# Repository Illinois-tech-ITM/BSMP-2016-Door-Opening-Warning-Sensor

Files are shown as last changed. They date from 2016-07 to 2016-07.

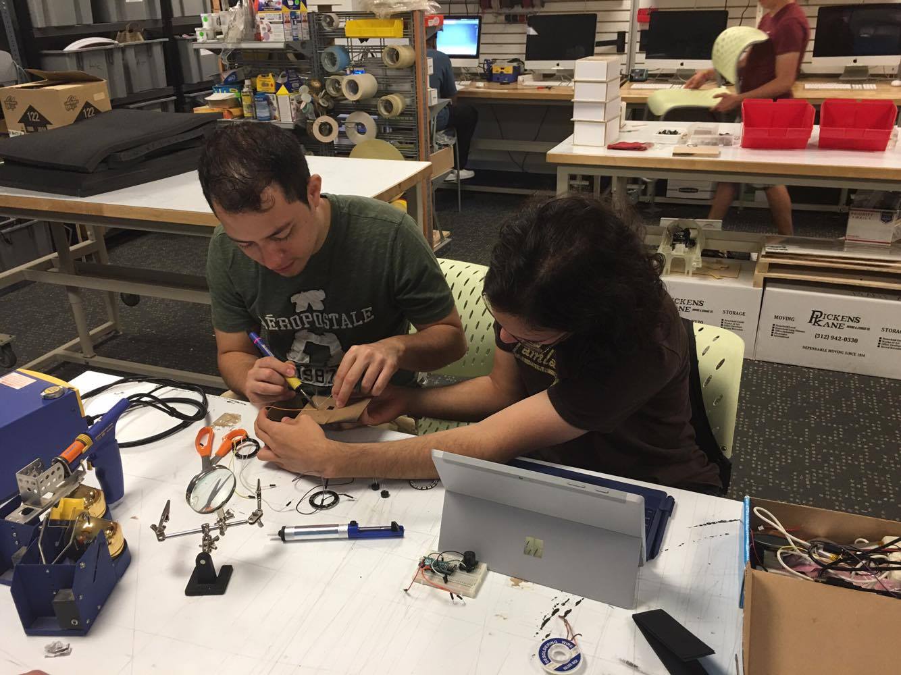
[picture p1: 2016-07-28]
Documents/Case Fabrication_2.jpg

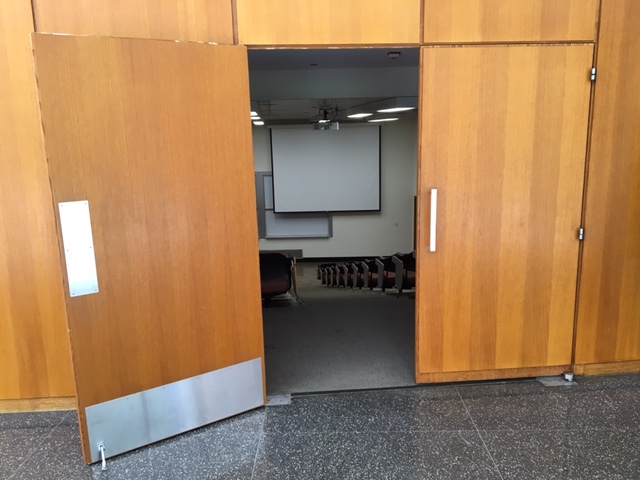
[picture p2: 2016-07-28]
Documents/Operating Door.jpg

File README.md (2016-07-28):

# BSMP-2016-Door-Opening-Warning-Sensor

This repo contains the code and schematics for creating an early warning system for people walking in creating an early warning system for doors opening into hallways

---------------------
### Participants
* Gabriel Filipe Botelho Barbosa ([@bestknighter](https://github.com/bestknighter))
* Guilherme de Castro ([@guidecastro](https://github.com/guidecastro))
* Luiz Gustavo de Marchi Brito
* Matheus Braz Duque
* Rodrigo Ferreira Abdulmassih

---------------------
### Instructions
If you want to reproduce this project, follow the steps below.

1. Download an Arduino IDE of your preference (we used their [official one](http://www.arduino.cc))
2. Build the project as in the [Fritzing diagram](/Documents/Diagram.png). _If you don't have a solar panel, you can ignore the solar panel charger and simply power it through the micro-usb._
3. Open the [main code](/Arduino_Micro_Code/Arduino_Micro_Code.ino) in the IDE.
4. Build and upload it. __Make sure to set the correct arduino model before uploading.__

You can tweak with the constants declared as Macros to calibrate the project for your use. The values in this repo is the one that worked best with us.

##### _Troubleshooting_

Problem | Solution | Reason
------ | ------- | --------
I uploaded the code and it is running excruciatingly slow/not running at all | If you're running with an external power, build the production version (comment all DEBUG defines). If you're powering with PC usb, open a serial monitor | This happens because the arduino waits the serial port to be read, halting the program until done so or until timeout (which takes usually too long)
Buzzer sounds but LEDs don't/LEDs lights up but buzzer don't | Check your cables to see if they are firmly attached, or change them, and plugged in to the right port described in the Macro areas | The signal may not be reaching the component due to a broken cable, loose cable or wrong port
Alarm does not behave as expected/is weird. | Callibrate your system by building the DEBUG version (uncomment just the `#define DEBUG`) and changing the constants. | Your case/scenario may be different from ours. Activating the debug mode allows you to understand what is happening and then change the constants value to what may fit best.

##### _Known Issues_
* When the distance with no one in front of the sensor is smaller than 2.5m and then someone enters (making the detected distance quickly reduce) is understood as someone walking towards the door, thus, triggering the alarm.
* The solar panel by itself can power the system and when the battery is charged can also power the system for a long time. But when the battery is plugged to the solar panel and powering the system, it stops working quickly. Using a power bank to power the system also works for a long time.

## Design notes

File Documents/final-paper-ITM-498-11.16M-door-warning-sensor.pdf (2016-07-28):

Illinois Institute of Technology School of Applied Technology Brazil Scientific Mobility Program

## Door Opening Warning Sensor

### 498UG Research Immersion Team

Prof. Jeremy Hajek

Gabriel Filipe Botelho Barbosa

Guilherme de Castro

Luiz Gustavo de Marchi Brito

Matheus Braz Duque

Rodrigo Ferreira Abdulmassih

Illinois Institute of Technology School of Applied Technology Brazil Scientific Mobility Program

Final Project report, Summer Research Program at Illinois Institute of Technology,

program provided and sponsored by the Brazilian government in

partnership with Institute of International Education.

### Door Opening Warning Sensor

Prof. Jeremy Hajek

Report regarding project research developed

by five Brazilian students during the period of

June 5 to July 26.

Illinois Institute of Technology School of Applied Technology Brazil Scientific Mobility Program

Summary

9. Personal Impressions

Illinois Institute of Technology School of Applied Technology Brazil Scientific Mobility Program

Introduction

Unfortunately, the media always emphasizes how safety matters are taken for granted

in the industry. It is not different when it comes to common areas or constructions, such as

houses, shopping centers and even university buildings.

Service doors, swinging or revolving, play a major role in domestic and industry

accidents. According to the U.S. Department of Labor’s Bureau of Labor Statistics, 17,800

non-fatal workplace door accidents were reported in 2003. Even though the safety regulations

are becoming stricter, from 2003 to nowadays, many accidents regarding service doors still

occurred.

It is known how fast Illinois Institute of Technology projects are growing and

consequently, the amount of people walking around campus and inside the buildings are

increasing as well. These facts draw attention to safety matters inside the facilities in order to

provide a harmless and efficient work environment.

The Wishnick Hall, built in 1945, is place of many events, seminars and presentations,

containing five classrooms and one auditorium. Throughout the years, the community noticed

that both doors, which give access to the auditorium, are not necessarily safe.

Both service doors are made of wood and are consequently heavy. The major issue is

how fast they open, due to an opening system. Consequently, many people have been injured

when walking outside the auditorium by the door.

The Door Opening Warning Sensor seeks to solve this human factor issue by

proposing and implementing a warning sensor inside the auditory, using a solar panel as its

energy source. The device would detect people inside and warn people outside, enhancing the

safety matter at Wishnick Hall.

Illinois Institute of Technology School of Applied Technology Brazil Scientific Mobility Program

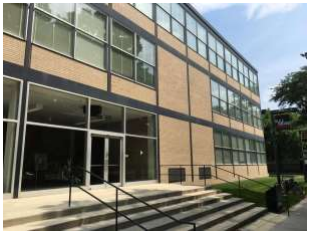
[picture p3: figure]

Figure 1 – Wishnick Hall at Illinois Institute of Technology campus.

Illinois Institute of Technology School of Applied Technology Brazil Scientific Mobility Program

Objectives

As the project title tells itself, the main objective is to propose a solution to the safety

matter at the auditorium of Wishnick Hall Auditorium. As explained in the introduction

section, when it comes to provide a harmless working environment, efforts should not be

measured.

The idea is to design and execute the further implementation of a warning sensor for

both auditory doors. Using a presence sensor, the device, as it detects a person approaching

the door, would emit a signal in order to warn people outside. The warning, searching for

maximum human factor efficiency, will be visual and audible as well.

Additionally, in order to achieve the community needs for environmentally friendly

systems, the whole warning device will be powered by solar panel. The project also includes,

as an objective, a study of how the glass, specifically the one used in the mentioned building,

influences the solar panel efficiency is providing the necessary energy to the warning device.

Illinois Institute of Technology School of Applied Technology Brazil Scientific Mobility Program

Materials list

Item | Quantity | Value per Item | Total Value per Item | Description
Solar panel | 1 | $29.00 | $29.00 | Medium 6V 2W Solar panel - 2.0 Watt
Controller | 1 | $24.95 | $24.95 | Arduino Micro with Headers - 5V 16MHz - (ATmega32u4 - assembled)
Charger | 1 | $17.50 | $17.50 | USB / DC / Solar Lithium Ion/Polymer charger
Tiny breadboard | 1 | $4 | $4
Half-size breadboard | 1 | $5.00 | $5.00
Battery | 1 | $9.95 | $9.95 | Lithium Ion Polymer Battery - 3.7v 1200mAh
Ultrasonic Distance Sensor | 1 | $29.99 | $29.99 | Parallax 28015 - Rev C
RGB Led ring | 3 | $9.95 | $29.85 | NeoPixel Ring - 16 x 5050 RGB LED with Integrated Drivers
Piezo Buzzer | 3 | $1.50 | $4.50 | Piezo Buzzer - PS1240
| | Total | $154.74

Table 1.0 – Material list, all taken from the Smart Technology & Embedded Systems Lab.

Table 2.0 – Material list, all taken from IDEA Shop, at IIT Campus.

Item | Quantity | Value
Used boxes | 2 | $0.00
Black paint spray | - | $0.00
General wires | - | $0.00
General tapes | - | $0.00
Flat cable | - | $0.00
Screws | 3 | $0.00

Illinois Institute of Technology School of Applied Technology Brazil Scientific Mobility Program

Solar Panel Experiment

Seeking to attend the global tendencies of renewable energy systems, the warning

sensor uses a solar panel, which model was specified in the Material List section of this

report. Due to logistics reasons and attempting to reduce the usage of extended wires along

the construction, the solar panel shall be installed inside the building.

To produce energy with a photovoltaic panel we need to mount the panel directed to

the sun. The process is simple, when the photons (particles of sunlight) hits the panel a certain

portion of it is absorbed within the semiconductor material. This means that the energy of the

absorbed light is transferred to the semiconductor. The energy knocks electrons loose,

allowing them to flow freely.

This project demand requires a study of how the glass, which separates the outside

area from the inside are of the building, affects the solar panel efficiency. Said that, a one-day

experiment was performed in order to measure the glass attenuation regarding the solar

radiation.

Starting at 8 am to 8 pm, running a step the experiment approximately each 3 hours,

the electric current and voltage were measured in a specific location inside and outside the

building.

The solar panel and multimeter, which models are specified in the Material List as

well, were used in order to collect the data shown in table 1 and 2 below. It is notable how the

average electric current and voltage varies within time of day and by the glass parameters.

Illinois Institute of Technology School of Applied Technology Brazil Scientific Mobility Program

Table 4.0 – Collected data, solar panel installed inside the building.

Analyzing the plotted charts, the expectations, based on the papers and studies

analyzed previous to the experiment, were accomplished. Right below, the electric current

data is shown for both cases of solar panel installation.

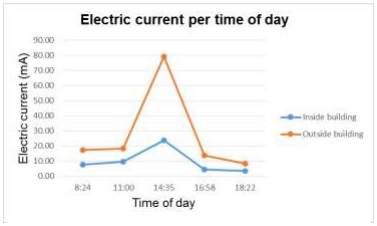
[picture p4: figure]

On the other hand, figure 3 shows how the voltage varies among time of day and

compare its values when the solar panel is located inside or outside the building.

Table 3.0 – Collected data, solar panel installed outside the building.

Experiment # | Time of day | Voltage (V) | Electric current (mA) | Standard Deviation
1 | 8:20 | 5.75 | 7.48 | 1.22
2 | 11:15 | 5.93 | 9.46 | 0.43
3 | 14:07 | 6.35 | 23.52 | 1.49
4 | 17:05 | 5.53 | 4.37 | 0.13
5 | 18:30 | 5.46 | 3.24 | 0.15
Experiment # | Time of day | Voltage | Average | Standard Deviation
1 | 8:24 | 6.29 | 17.18 | 2.36
2 | 11:00 | 6.22 | 18.23 | 0.29
3 | 14:35 | 6.83 | 79.22 | 6.66
4 | 16:58 | 5.96 | 13.52 | 0.89
5 | 18:22 | 5.86 | 8.17 | 0.35

Figure 2 – Comparison of electric current, provided by the solar panel, inside and outside the building.

Illinois Institute of Technology School of Applied Technology Brazil Scientific Mobility Program

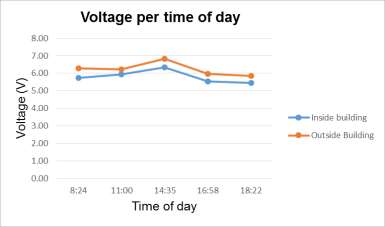
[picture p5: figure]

From the experiment, it is proved that the window’s glass really influenced the energy

production by the solar panel. This effect happened because the glass used on windows

nowadays receives special treatment to improve their ultraviolet and infrared reflections. This

glass is known as Low-emissivity Glass, and according to the U.S. Department of Energy it

has the capability to decrease up to 70% the heat provided by the sun.

That being said, it is confirm that when it comes to solar panels, more light means

more energy. As expected, experimental results showed that the solar panel, while installed

inside the building, achieved approximately 35% of capability to produce energy compared to

the installation outside the building.

Figure 3 – Comparison of voltage, provided by the solar panel, inside and outside the building.

Illinois Institute of Technology School of Applied Technology Brazil Scientific Mobility Program

Solar Panel

An experiment, which objective was to verify if the solar panel provides enough

power to the sensor system, was performed in the laboratory. A power source with variable

voltage setup was used in order to simulate the solar panel. A voltage of 6 V was settled in the

variable power source, based on the average voltage provided by the solar panel.

After soldering the capacitor on the Solar LiPoly Charger v2.0, which receives the

tension from the power source and distribute it to the battery and sensor system, the power

source was linked to the laboratory electrical system. Using a multimeter, it was verified that

6.2 V and 4.24 were distributed to the sensor system and battery, respectively.

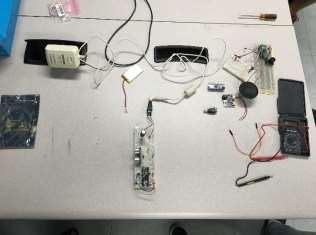
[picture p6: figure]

At first, even though the whole system was attached to the electrical system, the sensor

experienced an unstable period. The buzzer identified this stage, sonorously indicating that

the sensor was detecting someone even thought there was anyone on its range. After a while,

approximately 5 minutes later, the system started to work as expected. The most reasonable

explanation for that fact is the battery, which faced an unstable charging period and

consequently, the whole system was compromised for that period.

Figure 4 – Experimental apparatus and disposition.

Illinois Institute of Technology School of Applied Technology Brazil Scientific Mobility Program

Conclusively, based on this presented test and the last one, which verified that the

solar panel is capable of providing, in average, 6 V to the system, one solar panel is enough to

electrically feed the whole warning system.

Illinois Institute of Technology School of Applied Technology Brazil Scientific Mobility Program

Algorithm

### 1. Code progression through the project

One of the most important requirements of this project is to be responsive. The latency

between the distance between the sensor and the person needs to reflect as fast as possible in

the alarm. This yields in two main constraints code-wise: The distance sampling needs to

happen quite often and the decision of activating or deactivating the alarm needs also.

In our first iteration, we used a simple threshold for activating the alarm (i.e., if the

distance is smaller than X, activate the alarm, deactivate otherwise) and a direct sensor

sampling (i.e., the detected distance is considered to be absolute truth and taken without

noise). This first version met the constraints but not the requirements. The code executed

really fast and the alarm activated/deactivated immediately, but this was far from what we

needed. Not because it wasn’t fast enough, but because there were noise. Lots of noise. If

someone stood still in a specific distance, the alarm would activate and deactivate several

times per second.

Our approach was to use the libraries available to us made by the manufactures of our

components and hysteresis in the threshold. Those libraries exposed to us several methods for

noise handling. At this point, our code was somewhat usable enough to start calibrating to get

the specific values for our test case. This values are the maximum distance to trigger the

alarm, size of the hysteresis, amount of noise reduction needed, etc.

As we were measuring for the first time, we noticed that we went to the other side of

the scale, now having a really slow sampling code but with good decisions. After some brute-

force debugging we found the issue: the libraries was executing a blocking code. To be able to

Illinois Institute of Technology School of Applied Technology Brazil Scientific Mobility Program

deal with the noise, the library was sampling the distance several consecutive ways, then

calculating the mean, and then returning the control to the rest of the code. This was

consuming a lot of the time that could be used to calculate whether or not to activate the

alarm.

In the third code iteration, we decided to sample the sensor with no noise at all and

write our own non-blocking noise reduction code. We also added a control state to know the

direction of the movement of the person and we already wrote this with hysteresis. After some

testing to determine the intensity of the noise reduction algorithm, we had a robust, fast and

efficient algorithm that could not only do what we needed to do but also do it in a small

amount of time.

The next step would be to do a code cleanup to reduce the size (removing unused

libraries and only importing the functions used), refactor it to separate the algorithm that

decides what to do from the algorithm that turns on or off the alarm, using hardware

interruptions for distance sampling and optimize the non-blocking code further to have fewer

time-consuming assembly operations (e.g., instead of moving the whole queue to add a new

sampled distance, just replace the older one).

### 2. Algorithm overview

First of all, to reduce Arduino’s RAM usage, our constants are Macros defined in the

header. The downside is the increased compilation time, but nothing too much to be

impossible to wait.

Illinois Institute of Technology School of Applied Technology Brazil Scientific Mobility Program

In the setup function, our code creates and initializes the C++ objects for interfacing

with the LED Ring and to sample the sensor (required by the libraries). If it’s a debug build,

the Serial port will also be initialized.

Our main function can be divided in three parts: data gathering, data extrapolation and

behaviour control. The data gathering is for collecting and cleaning the data. The data

extrapolation part is to extrapolate and “understand” what is happening in the environment.

The last part is actually interfacing with our outputs, LEDs and buzzers.

In the data gathering part, our code first sample the distance once and then push it to a

fixed size queue implemented using a simple vector. Then it sums up all the elements of this

vector and divide it by the size of the vector, thus, reducing the noise through a low-pass

filter. The result of the division is the “clean distance”. This distance is compared to the last

clean distance detected and this is the delta value.

In our data extrapolation part, we first use the delta value to know the direction of the

person. If delta is negative, it’s approaching. If delta is zero, it’s stopped. If delta is positive,

it’s distancing. We didn’t used the absolute value but instead we used hysteresis. So, to our

system say that someone started approaching when it was stopped, the delta needs to be, for

example, -1.5 but to be considered standing still after approaching it needs to be -0.2, instead

of 0 in this two cases.

Our code also uses the cleaned distance to know if the person is in the danger zone

(closer than the maximum threshold) or not and also compute for how many consecutive loop

iterations it has been in this state (e.g., approaching for 40 loop iterations, stopped for 3 loop

iterations, etc) up to a maximum.

Illinois Institute of Technology School of Applied Technology Brazil Scientific Mobility Program

In the last part, the algorithm will look to those extrapolated data turn on or off the

alarm based on that. For example, if it’s approaching for more than 5 consecutive loops,

activate alarm, if it’s stopped or distancing for more than 30 consecutive loops, deactivate the

alarm. The alarm is made of buzzers and LEDs. The buzzers have their ground and their

signal pins connected together since their impedance are low enough to do that without losing

loudness. They are activated by a simple tone function in one pin. The LEDs use a library to

ease their use but what our code needs to do is set up all the desired colors for all LEDs and

then send the command to the driver through the pin. After this, the loop restarts.

Illinois Institute of Technology School of Applied Technology Brazil Scientific Mobility Program

Conclusion and further steps

Regarding all the previous stated objectives for the 2016 Summer Research project, it

is safe to say that all the main objectives were accomplished. Even though the time could have

been a compromised factor, the team managed to research, design, test and implement the

prototype for the Door Opening Warning Sensor.

Each of the team members agreed that a great amount of effort was put on the project

and therefore, a high level of knowledge was acquired. Each member played an important role

since the sparkling initial idea until the prototype installation and testing.

Both sections, the software as well as the hardware, worked as expected in the

auditorium at Wishnick Hall. The algorithm works for many different cases, turning the whole

product in a versatile and functional device. Additionally, the warning device, a box which

contains three LEDs and 3 buzzers, works for people with disabilities as well and can be seen

by many angles. All these factors, considering performance, safety and applicability were

thought and developed during the project.

Conclusively, the prototype was successfully made and tested and, from now on, as

every technological/engineer project, it can be optimized. The warning devices can be

changed to more user-friendly ones and regarding the sensor, it can be replaced by one with a

larger range. The main power source could also be improved or changed depending the

location, among other improvements and optimizations.

Hopefully, the prototype is an additional spark for the development and improvement

of warning systems, always looking for durable, safe and efficient solutions for human factor

problems.

Illinois Institute of Technology School of Applied Technology Brazil Scientific Mobility Program

Bibliography

1. Azezova, N. R., & Azezov, R. R. (n.d.). Impact of Solar Radiation Attenuation Coefficient of Translucent Cover Material on Heat Efficiency of “Translucent Cover– Radiation Absorbing Heat–Exchange Panel” System of Flat Solar Collectors. Retrieved June 14, 2016.
2. Azezova, N. R., Azezov, R. R., & Samiev, K. A. (n.d.). Effective Reflectivity of “Transparent-Cover–Radiation- Absorbing Heat-Exchange-Panel” System of Flat Solar Collectors. Retrieved June 14, 2016.
3. Caram, R. M., Pizzutti, J., Labaki, L. C., & Sichieri, E. P. (n.d.). Evaluation of Solar Radiation Transmission Through Transparent Facades. Retrieved June 15, 2016.
4. Industrial Door Safety. (n.d.). Retrieved June 20, 2016, from https://ohsonline.com/Articles/2005/12/Industrial-Door-Safety
5. Introducing Trinket. (n.d.). Retrieved June 8, 2016, from https://learn.adafruit.com/introducing-trinket/introduction
6. Maxbotix Ultrasonic Rangefinder. (n.d.). Retrieved June 13, 2016, from https://www.adafruit.com/products/979
7. Medium 6V 2W Solar panel. (n.d.). Retrieved June 8, 2016, from https://www.adafruit.com/products/200
8. Wishnick Hall. (n.d.). Retrieved June 8, 2016, from https://web.iit.edu/event-services/meeting-spaces/academic-space/wishnick-hall

Illinois Institute of Technology School of Applied Technology Brazil Scientific Mobility Program

Individual impressions

### 9.1 Gabriel Filipe Botelho Barbosa

Even though that the Door Opening Warning System is not the first research

program that I am participating in, it is the first that I was expected to develop a full fledged

and working prototype by the end. The fact that I would need to interact and collaborate with

colleagues from different areas of knowledge and that I would be in close contact with

hardware development were major keys to make me interested.

I saw this opportunity as a way to sharpen some of my skills and to learn more about

things I didn’t had much knowledge nor practical experience such as multi-disciplinary group

collaboration and management, prototyping, arduino programming and optimization. By the

end of this research project, new ways of approaching a problem, new point of views and a

new mindset are also a few of the skills that I am proudly adding to my skillset on my way

home.

Having access to a lot of high-level and quality, state-of-art resources ranging from

tools to components in the Smart Technology & Embedded Systems Lab and also in the Idea

Shop made a huge difference. It allowed us to develop the solution in our pace, without

tool/component bottlenecking, with a better quality than what is expected from a prototype.

Having such a diverse group was by itself an awesome experience, allowing us to

work in what we know best and trusting that the other would do so in their areas. As I am a

Computer Engineering student, I was assigned to work with hardware interfacing

programming (i.e making buzzer to sound, LEDs to blink, distance sampling through the

sonic rangefinder, sensor data cleaning, etc), light optimization for small-memory devices and

pseudo-concurrent algorithms implementation. One more good thing about working with a

Illinois Institute of Technology School of Applied Technology Brazil Scientific Mobility Program

group with different backgrounds is that you learn a lot from each other, both theoretical and

practical skills, from areas where you hardly would get contact with.

One thing that I would like to highlight from this experience is the freedom and lack

of bureaucracy in regards to how the problem should be tackled and in getting access to all

resources needed. It was quick and easy to find and use everything needed. Having such a

high-paced environment to work with allowed us to have enough time to fulfill the

expectations and meet the deadline with ease. I would say that it was quite similar to the

hacking atmosphere found in hackathons and that is awesome.

I, together with the whole team, am happy with the end result. The final prototype

worked really well and demonstrated that a large scale production of a more robust product is

possible. There still is a need to analyze the viability but since the code and the hardware

design is simple, I believe that it is viable to produce it in industrial scale for commercial use.

I am really thankful for being accepted in the Science Without Borders program. I

would like to thank Illinois Institute of Technology for accepting me and God for giving me

opportunities to grow, to learn and to be able to exceed the expectations upon me wherever I

come to be.

Illinois Institute of Technology School of Applied Technology Brazil Scientific Mobility Program

### 9.2 Guilherme de Castro

Working on the Door Opening Warning Sensor project was a very good opportunity to

me, even though I also think that it was challenging. When professor Hajek introduced us to

the problem and to the project I was very curious about how that would work and how we

would do it.

That was the first time in my life dealing with a project strongly related to hardware.

At that point I had zero knowledge of how to work with sensors, Arduino and electrical

circuits. After that, I started to talk and get to know my teammates better, it was very exciting

because we all were from different fields. Everyone was already suggesting ideas on how to

start and what we could do. My teammates are Gabriel, who studies Computer Engineering;

Matheus, who studies Electrical Engineering; Rodrigo, who studies Mechanical Engineering

and last, but not least we have Luiz Gustavo, who studies Automation Engineering.

I was very impressed with this group because everyone had something to share and to

contribute with the project, we are a very strong and solid based team. We have people who

know how to project the circuit and how to properly supply power to it, we have people to

deal with sustainability since we work in an environmental friendly project powered by solar

energy, they made an amazing job measuring and analyzing if only one solar panel was able

to provide enough energy to maintain our system working. Furthermore, we also have people

coding, doing the logic and testing the sensor. That doesn’t mean we were only dealing with

problems related to our majors and were in our comfort zone, we were all involved with all

parts in this project.

I learned a lot during this project, I learned how to use Arduino which was a life

changing experience, before coming here I had heard about it, but never had I done anything

Illinois Institute of Technology School of Applied Technology Brazil Scientific Mobility Program

with it. I also learned how to use C++ for the first time, I was only used to using C# and Java.

It was very difficult in the beginning and I was pretty much helping Gabriel, who had plenty

experience with Arduino and C++, understand the problem and test the sensor. I improved my

knowledge on that as we were working, Gabriel was very patient and taught me a lot of things

while we were working on this project. I also learned how to deal with GitHub, because I had

used it only once. It was a very nice experience, I learned how to deal with a very annoying

bug and how to solve it. I discovered a pretty nice tool to it. We had this problem when we

committed the code and me and Gabriel had changed the same part on the code, that was

generating a conflict. To find and to solve this kind of problem is very difficult and takes a lot

of time, so I talked to a friend and he gave me tips on how to solve that. I found a very nice

tool called “vimdiff”, this saves a lot of time and is something I’ll use in another projects from

now on.

At the testing and implementation phase we went to the Idea Shop and we met this

really nice guy who runs the lab, his name is John. There we created the boxes where all our

hard work fitted in. He was very attentive and gave us some advices and all the needed tools

to crave, paint and build the boxes. After two days working there, we achieved the final

prototype, and I was very impressed by it. It was way better than I thought it would be, the

team did an amazing job on that.

Overall it was a great project and I’m very proud of what we did. This project has a

real impact in the world and can be used to prevent accidents that can seriously injure people.

We had less than two months and we delivered a 100% functional prototype. IIT facilities and

professor Hajek provided all the tools and materials needed to accomplish this outstanding

result. Personally, I learned a lot about different fields of study and I’m very thankful for this

Illinois Institute of Technology School of Applied Technology Brazil Scientific Mobility Program

opportunity to challenge myself to work in group, make connections with people I can work

with in the future and to learn, be inspired and curious about things I didn’t know before

coming here. It was a great summer! Thanks to everyone I worked with and/or helped me

somehow.

Illinois Institute of Technology School of Applied Technology Brazil Scientific Mobility Program

### 9.3 Luiz Gustavo de Marchi Brito

This summer I had an incredible opportunity of working in a Project called Door

Warning Opening Sensor at the Illinois Institute of Technology. Our group consisted of 5

students, and each one of us have a different major; so we could manage almost every single

problem that occurred on the development and on the tests that we made with our prototype.

We were led by Professor Jeremy Hajek; he was extremely helpful every time that we

needed his assistance; also, he gave us the liberty to apply our own ideas on the project, or to

change any previous specification to make improvements and a better final product, which is

our main goal.

Our product can increase the security and make public places safer by warning people

approaching a heavy service door from the inside of a building.

In a short period of time we produced a working and usable prototype that met and

exceed the pre requisites. This is a remarkable result, because we had just 7 weeks to work on

this project, and we did not have any previous material, so all progress that we made is our

merit.

We divided our work timeline in steps. First, we thought about the problem, and we

tried to came up with the best solution for the problem combined with an user friendly device.

Then, we had to design a prototype that will be installed in public spaces, so the appearance

has to be taken into consideration.

After designing the prototype we started building it, and we really got our hands dirty.

We worked in a lab called Idea Shop the most part of the building stage. We had several

different tools available for use on this lab, which increased our productivity and chance of

succeed.

Illinois Institute of Technology School of Applied Technology Brazil Scientific Mobility Program

The last part of our project was testing the prototype in a real life situation, and it was

taken place in the auditorium that motivate the initial idea of this product. The final result of

the testing stage was outstanding.

I am really grateful for what we accomplished with this project. We improved and

learned a variety of skills such as coding, Arduino kit, welding, designing, prototyping. Our

entire group was linked and motived to deliver the best result possible.

Finally, I would like to thank the IIT for accept my application; to professor Hajek for

being helpful and accessible all time; and to my teammates that made this summer an unique

experience, working with them was a pleasure.

Illinois Institute of Technology School of Applied Technology Brazil Scientific Mobility Program

### 9.4 Matheus Braz Duque

Studying abroad had been my dream since my teenage. However, I have never

imagined that some day I would not just study abroad, but also work in a research project in

one of the best colleges in the US.

My first experience was meeting my research team, composed by students with

different majors: Gabriel Filipe Botelho Barbosa, a Computer Engineering student, Guilherme

de Castro, an Information Systems student, Luiz Gustavo de Marchi Brito, an Automation

Engineering student, and Rodrigo Ferreira Abdulmassih, a Mechanical Engineering student. I

really enjoyed the way the team was created because with such a variety we had different

points of view about the same questions, so each one could contribute with different ideas and

the team could reach higher levels of solutions.

During the development of the Door Opening Warning System research project, with

prof. Jeremy Hajek, we had free access to a variety of tools and devices. It was an incredible

experience, since we did not have time issues like waiting for some device to be bought or

shipped and all tools were available anytime we needed. I liked the way the professor trusted

in us; he made us feel free to develop without unnecessary restrictions. We had direct access

to any equipment, without bureaucracy. This trust-based relationship helped the group to

advance much faster.

Another important knowledge I got in my experience here is strongly related to my

objective to become a professor. Research projects are common activities for a professor

nowadays. Here in Illinois Institute of Technology, I could experience this activity and

observe how a professor leads a research team, how the resources are shared among the

teams, how to integrate students from different majors, and how to use online tools, such as

Illinois Institute of Technology School of Applied Technology Brazil Scientific Mobility Program

Trello and GitHub, to verify if the students are dedicating properly and how they are

advancing. With these tools, a professor can easily keep up with his students and know what

they are doing, even at distance. For sure it was a valuable experience for me and it is going to

be useful in my career as a professor.

Finally, my campus life experience was amazing. Due to the infrastructure provided

by IIT to the students who live in campus, I could enjoy my free time much more. I have

made new friends here; some of them I met playing volleyball, others in the dinning… I

believe it is also an important aspect to consider in a college. IIT is a complete college,

because it provides the student with both academic and non academic resources, preparing

him for his professional life.

I am thankful to God for the opportunity I received to experience this whole thing. For

sure, my experience in IIT changed me and I will never forget it.

Illinois Institute of Technology School of Applied Technology Brazil Scientific Mobility Program

### 9.5 Rodrigo Ferreira Abdulmassih

Since the beginning of the project, I knew that the summer of 2016 would be a

challenge. It was clear how much expectation the Institute of International Education (IIE)

and the Illinois Institute of Technology (IIT) itself had on us. Developing a group project, on

which five people that have never met before need to achieve a high level of efficiency and

develop an outstanding project, sounded like an amazing opportunity.

Door Opening Warning Sensor. At first, the project title caught my curiosity and

inspired me to learn more about sensors and electronics, topics that I did not have much

knowledge on. Our group, formed by five Brazilian students, is very dynamic and versatile.

The fact that we are very different from each other is what made our group efficient and gave

us the necessary strength to face, analyze and solve problems.

The first main idea was to prevent accidents in an auditorium on IIT campus. After

visiting and studying the local, our group decided that we could expand the range of our

project. Obviously, the idea was to develop a solution for the suggested local. However, we

decided to expand it and make the device as versatile as possible, so it could be applied in any

operating door.

As we all have different skills, we could help and learn from each other during the

entire project. Since the beginning, when we were brainstorming about the project steps, it

was clear how each group member would help work during the project.

One fundamental factor was Professor Hajek, who gave us the necessary help and

support. He amazingly balanced the equilibrium between supporting the group and at the

same time, letting the group think and develop ideas by itself. The laboratory, named as Smart

Illinois Institute of Technology School of Applied Technology Brazil Scientific Mobility Program

Technology & Embedded Systems Lab, was an indispensable factor for the project

development.

All the devices, pieces and tools were easily found in the lab. In addition to that,

Professor Hajek was also very proactive for ordering/buying any device the lab did not have

at the moment. The Idea Shop, a student lab, was also very helpful for manufacturing the

cover boxes. All the material, including boxes, tape, painting materials, strews, and other

items were provided. John, the responsible for the student lab, was also very helpful and

played an important role giving tips and advice for the manufacturing process.

I consider myself very organized and analytical, skills that I applied on the

management and organization of all the steps developed during the project. Additionally, the

circuit cover box manufacturing process and the solar panel study was the area that I could

apply the most my Mechanical Engineer skills. It was interesting how broad ours project was.

We did theoretical studies, experimentations, coding, manufacturing and finally, installation

and testing. All the present steps in any engineering or technological company.

Personally, I learned a lot regarding sensors, C++ programing, circuits and Arduino

kit. Applying the theoretical knowledges learned in class in a real group project was an

amazing experience. It is also interesting to notice the social skills all the group members

developed. Of course we had our differences, but in the end, we managed it very well and

developed a functional and high quality Door Opening Warning Sensor device.

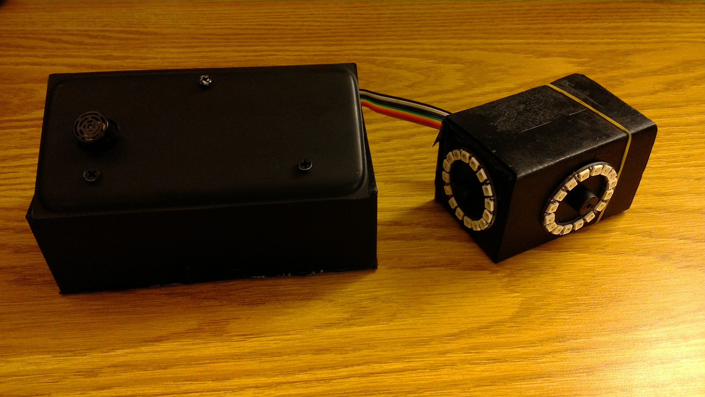
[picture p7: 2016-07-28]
Documents/Final Prototype Iteration.jpg

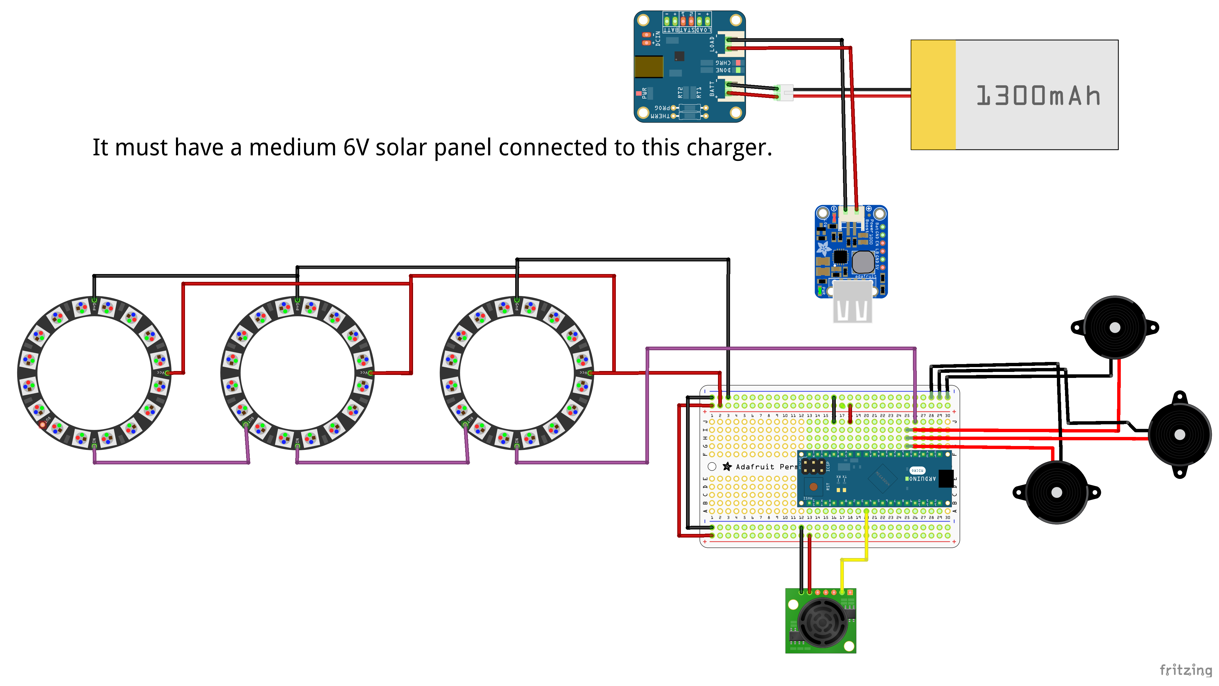
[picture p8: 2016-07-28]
Documents/Diagram.png

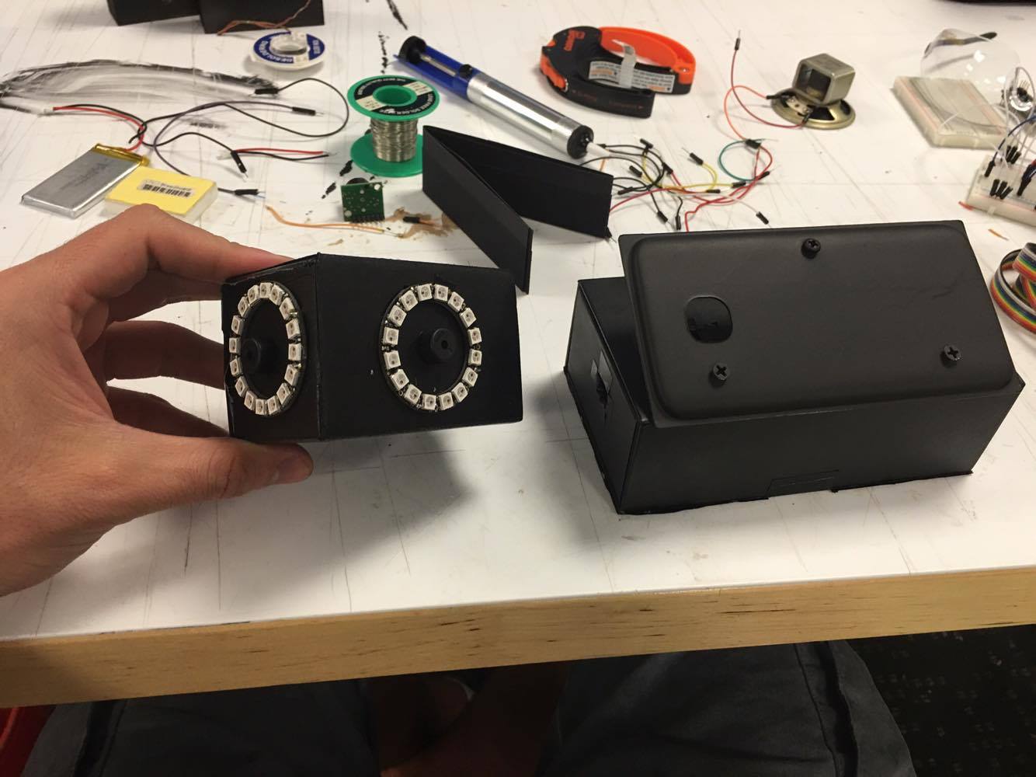
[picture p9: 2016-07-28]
Documents/Final Prototype Cases.jpg

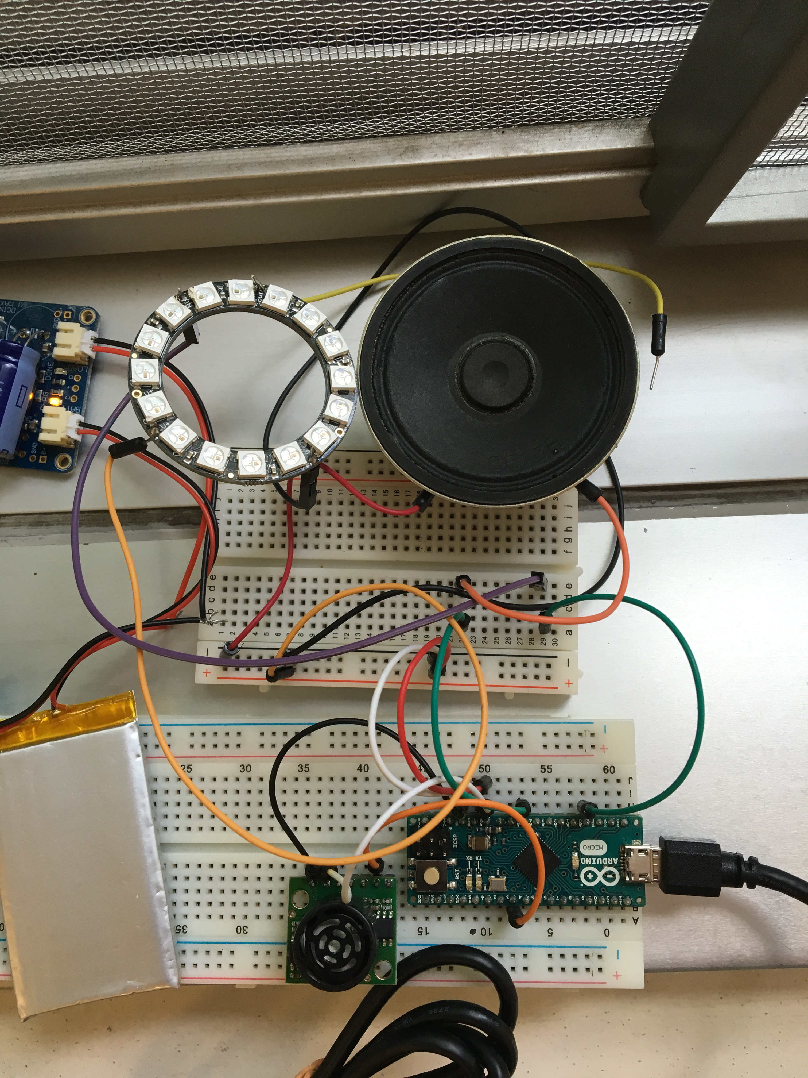
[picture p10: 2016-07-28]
Documents/Second Prototype Iteration.jpg

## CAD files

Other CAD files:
Documents/Auditorium_sketch.dwg

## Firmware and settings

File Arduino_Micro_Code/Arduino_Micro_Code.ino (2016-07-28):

#include "Maxbotix/Maxbotix.h"   // Library of Sonic Rangefinder
#include "NeoPixel/Neopixel.h"   // Library of LED Ring

#define SONIC_SENSOR_PIN 3  // Pin where the Sonic Rangefinder Controller is
#define SOUNDPIN A1         // Pin where the buzzer signal will be sent
#define SOUNDFREQ 440       // Sound Frequency of Buzzer
#define LEDPIN A0           // Pin where warning NeoPixel ring is
#define NUMPIXELS 48        // Total number of pixels in all NeoPixel rings
#define MAXDIST 200         // Maximum distance (in cm) to be "too far away from door"
#define SAMPLE_SIZE 30      // Number of samples to analyze to decide if warning should continue ringing
                            // (affects how long someone needs to be stopped or distancing from door for the warning to stop)
#define KERNEL_SIZE 10      // Size of the low-pass filter
                            // (bigger kernel yields less noise but more response latency)


//#define DEBUG             // Activate all debug messages
//#define DEBUG_APPROACH    // Activate debug messages of the approaching handler
//#define DEBUG_FILTER      // Activate debug messages of the low pass filter
//#define DEBUG_WARNING     // Activate debug messages of the LED and buzzer controller


/***************************************************
 *  Functions, Enums and Global Vars declaration   *
 ***************************************************/
float lerp(float A, float B, float i);        // Linear Interpolation from A to B controlled by i [0-1]
void toggleWarning();                         // Toggles the warning state (turn LEDs and buzzer on and off)
void solid(uint8_t R, uint8_t G, uint8_t B);  // Puts all LEDs of the ring with the same color (0,0,0 to turn off)
void pushToFilter(float value);               // Add the next read value of distance in to the low pass filter kernel
float updateMean();                           // Updates the global var treatedRange with the new filtered value (and returns its value)

enum ObjectState {    // Enum of possible movements of a detected person
    APPROACHING,
    STOPPED,
    DISTANCING
};

Maxbotix rangeSensorPW(SONIC_SENSOR_PIN, Maxbotix::PW, Maxbotix::LV, Maxbotix::NONE);     // For using the sonic rangefinder
Adafruit_NeoPixel pixels = Adafruit_NeoPixel(NUMPIXELS, LEDPIN, NEO_GRB + NEO_KHZ800);    // For controlling LED ring
float ranges[KERNEL_SIZE];      // Kernel for low pass filter (array with last KERNEL_SIZE measures)
float treatedRange;             // Range after filtering
ObjectState state = STOPPED;    // Actual movement of the person



/********************************
 *  Arduino-Specific Functions  *
 ********************************/
void setup() {
  #if defined(DEBUG) || defined(DEBUG_APPROACH) || defined(DEBUG_FILTER) || defined(DEBUG_WARNING)
  {
    Serial.begin(9600);
    while(!Serial);
  }
  #endif // DEBUG || DEBUG_APPROACH || DEBUG_FILTER || DEBUG_WARNING
    pixels.begin();
    pinMode(SOUNDPIN, OUTPUT);
} // setup

void loop() {
    static byte notApproachingCount = 0;   // For controlling when to stop the warning even within danger range
    static byte approachingCount = 0;      // For controlling when to re-start the warning
  
    pushToFilter(rangeSensorPW.getRange());         // Distance (in cm) of closest detected object from Sonic Rangefinder
    float delta = -(treatedRange - updateMean());   // Change in the distance from last measurement

    // A delta of more than 26 cm every 25ms (approx. 10 m/s) is probably an error on the detected distance
    if (delta > -26 && delta < 26) {    // so we just ignore that case
        if (delta < -1.5) {             // Someone is approaching if its distance is decreasing by more than 1.5 cm
            state = APPROACHING;
        } else if (delta > 1.5) {       // Someone is distancing if its distance is increasing by more than 1.5 cm
            state = DISTANCING;
        } else if (delta > -0.5 && delta < 0.5) { // Someone stopped moving if its distance is changing by less than 0.5
            state = STOPPED;
        } // if-2x_else_if delta
    } // if |delta| > 26
  #if defined(DEBUG) || defined(DEBUG_FILTER)
  {
    for(int i = 0; i < KERNEL_SIZE-1; i++) {
      Serial.print(ranges[i]);Serial.print(" | ");    
    }
    Serial.println(ranges[KERNEL_SIZE-1]);
    Serial.print("Mean: ");Serial.println(treatedRange);
    Serial.print("delta: ");Serial.println(delta);
  }
  #endif // DEBUG || DEBUG_FILTER
  #if defined(DEBUG) || defined(DEBUG_FILTER) || defined(DEBUG_APPROACH)
  {
    Serial.print("State: ");Serial.println(APPROACHING==state? "Approaching" : STOPPED==state? "Stopped" : "Distancing");
  }
  #endif // DEBUG || DEBUG_FILTER || DEBUG_APPROACH
  #if defined(DEBUG) || defined(DEBUG_APPROACH)
  {
    Serial.print("approachingCount = ");Serial.println(approachingCount);
    Serial.print("notApproachingCount = ");Serial.println(notApproachingCount);
  }
  #endif // DEBUG || DEBUG_APPROACH
    if (APPROACHING == state) {         // If person is approaching
        // Increase counter of consecutive times the person is approaching
        approachingCount = approachingCount<2?approachingCount+1:2;
        if (approachingCount >= 2) {    // If the counter is >= 2, it's not due to noise
            notApproachingCount = 0;    // Reset counter of consecutive times the person is stopped or distancing
        } 
    } else {      // If person is not approaching (i.e. it's stopped or distancing)
        // Increase counter of consecutive times the person is not approaching
        notApproachingCount = notApproachingCount<SAMPLE_SIZE?notApproachingCount+1:SAMPLE_SIZE;
        approachingCount = 0;           // Reset counter of consecutive times the person is approaching
    } // if-else approaching == state

    // If person is too far OR not approaching for SAMPLE_SIZE consecutive readings, turns off warning
    if (treatedRange > MAXDIST || notApproachingCount >= SAMPLE_SIZE) {
        noTone(SOUNDPIN);   // Turn buzzer off
        solid(0,0,0);       // Turn LED ring off
    } else {      // Turn warning on otherwise
        /*  The program enters this section in the following conditions
         * - When the distance of person is smaller than MAXDIST, AND
         * - one of the following happens:
         *  -- The person is approaching
         *  -- OR, the person is stopped/distancing for less than SAMPLE_SIZE consecutive readings
         */
        float period = lerp(0, 100, treatedRange/MAXDIST);   // Toggle period in ms, linearly interpolated by the distance
        static unsigned long t_start = 0;     // Stores when warning state changes
        unsigned long m = millis();           // Stores when was the last time the code went through this part
      #if defined(DEBUG) || defined(DEBUG_WARNING)
      {
        Serial.print("LED delay: ");Serial.print(period);Serial.println("\tms.\t");
        Serial.print("t_start: ");Serial.print(t_start);Serial.print("\tms.\t");
        Serial.print("m: ");Serial.print(m);Serial.print("\tms.\t");
        Serial.print("m-t_start: ");Serial.print(m-t_start);Serial.println("\tms.\t");
        Serial.println();
      }
      #endif // DEBUG || DEBUG_WARNING
        if(m - t_start >= period) {     // Toggle LED ring and buzzer if the last time that that happened was more than period ms ago
            t_start = millis();
            toggleWarning();
        } // if toggle
    } // else turn warning on
  #if defined(DEBUG) || defined(DEBUG_APPROACH) || defined(DEBUG_FILTER) || defined(DEBUG_WARNING)
  {
    Serial.println("\n-----------------------------------------------\n");
  }
  #endif // DEBUG || DEBUG_APPROACH || DEBUG_FILTER || DEBUG_WARNING
} // loop



/*******************
 *  Our Functions  *
 *******************/
float lerp(float a, float b, float i) {   // Linear Interpolation from A to B controlled by i [0-1]
    return (1-i)*a + i*b;
}

void toggleWarning() {      // Toggles the warning state (turn LEDs and buzzer on and off)
    static boolean warningOn = false;    // Controls the warning intermitence
    
    if (warningOn) {
        noTone(SOUNDPIN);
        solid(0,0,0);
    } else {
        tone(SOUNDPIN, SOUNDFREQ);
        solid(255,0,0);       // Brightest red possible
    }
    warningOn = !warningOn;
}

void solid(uint8_t R, uint8_t G, uint8_t B) {     // Puts all LEDs of the ring with the same color (0,0,0 to turn off)
    for (int i = 0; i<NUMPIXELS; i++) {
        pixels.setPixelColor(i, pixels.Color(R,G,B));
    }
    pixels.show();
}

void pushToFilter(float value) {      // Add the next read value of distance in to the low pass filter kernel
    for(int i = 0; i<KERNEL_SIZE-1; i++){   // Shifts all values 1 position to the left in the array
        ranges[i] = ranges[i+1];
    }
    ranges[KERNEL_SIZE-1] = value;
}

float updateMean() {      // Updates the global var treatedRange with the new filtered value (and returns its value)
    float m = 0;
    
    for(int i = 0; i<KERNEL_SIZE; i++){     // Sums the array
        m+=ranges[i];
    }
    return treatedRange = m/KERNEL_SIZE;
}

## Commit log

2016-06-13 LED lights up when too close
    [Arduino_Micro_Code.ino]
2016-06-15 Create a sample variable, peak handling and fixed pointer
    [Arduino_Micro_Code.ino]
2016-06-22 Changed Sonic Rangefinder
    Changed for a more suitable sensor for person detection
2016-06-27 Changed single LED to NeoPixel LED ring
2016-06-28 Primitive noise handling added
    Still needs to be perfected but it's already kind of working
    [Arduino_Micro_Code.ino]
2016-06-29 Started adding a low pass filter to data
2016-06-29 Fixed Debug code for filter
    [Arduino_Micro_Code.ino]
2016-06-30 Low pass filter, Comments and code formatting
    The low pass filter was finalized and tested.
    Code is now extensively commented.
    Changed tab from 2 spaces to 4.
2016-07-12 Battery level libraries
2016-07-13 Added rough battery monitor for testing
2016-07-18 Reversing last three commits
    Battery level can be monitored by hardware
    [Arduino_Micro_Code.ino]
2016-07-28 Switching to production build
2016-07-28 Added more images
    [Auditorium_sketch.dwg]
2016-07-28 Added Fritzing Diagram file and Final Paper
    [Fritzing_Diagram.fzz]
